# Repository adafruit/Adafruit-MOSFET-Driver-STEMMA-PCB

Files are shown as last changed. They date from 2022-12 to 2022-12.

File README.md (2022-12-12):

## Adafruit Adafruit MOSFET Driver STEMMA PCB

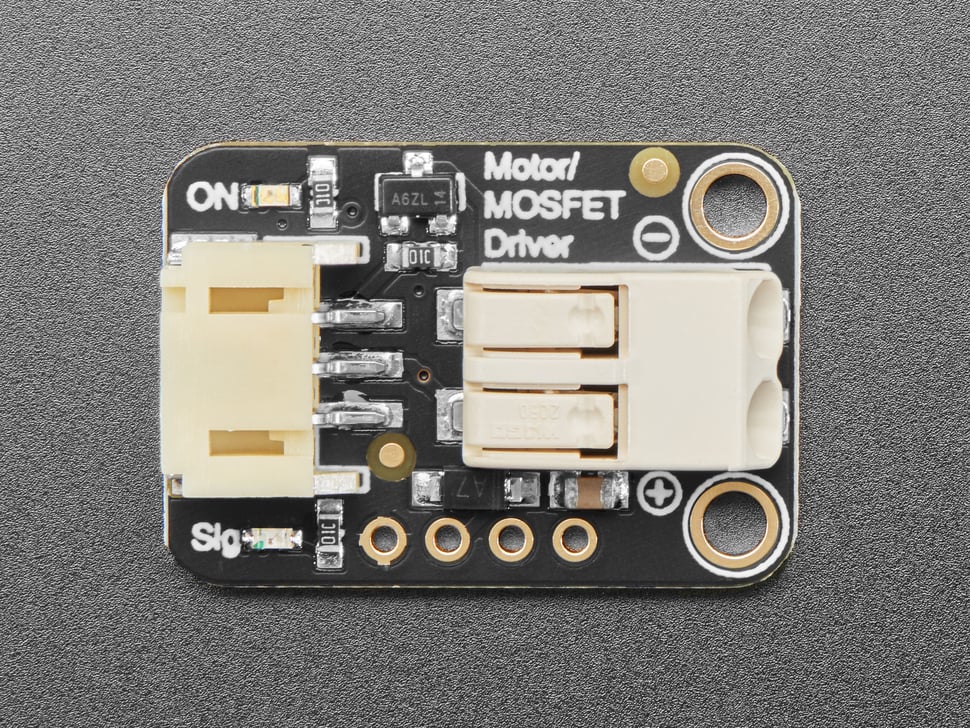
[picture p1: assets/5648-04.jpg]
<a href="http://www.adafruit.com/products/5648"><br/>
Click here to purchase one from the Adafruit shop</a>

PCB files for the Adafruit Adafruit MOSFET Driver STEMMA. 

Format is EagleCAD schematic and board layout
* https://www.adafruit.com/product/5648

### Description

Sparky the Blue Smoke Monster shows up whenever the magic smoke is let of of an electronic component. And his very favorite is whenever folks first start with electronics and robotics: wiring up a motor or solenoid or high power LED is a perfect recipe for getting that blue smoke out of an Arduino or Raspberry Pi. Why? Because these high-current devices can't be connected directly to a GPIO pin on a microcontroller! They need to have a transistor / MOSFET driver, plus a kickback-protection diode that will absorb the inductive 'kick' caused by turning on-and-off motors and solenoids. Without that driver and diode - your tronix will go poof!

We have tutorials on how to wire up the components to create a transistor driver on a breadboard, but its easy to put the diode in backwards, or pick the wrong kind of transistor. And some folks don't want to have the extra breadboard for just controlling a simple motor fan or solenoid. Which is why we designed the Adafruit STEMMA MOSFET Driver for Motors, Solenoids, and LEDs. 

This board has a simple plug-and-play JST PH (2mm pitch) input connector for solderless use. Provide power (from 3V up to 30V) and signal (3V to 20V logic level). On the output are two-output terminal blocks, with one block connected to power and the other switched to ground when the signal level is high. In between is an AO3406 N-Channel MOSFET rated for  30Vds, 3.6A peak, and 70mΩ RdsOn plus a 1N4007 flyback diode.

You can also get to all the signal and power pins on a 0.1" breakout header if desired, but we expect most folks will like using it as a solderless MOSFET-buddy. Great for driving motors, inductors, high power LEDs, single-color LED strips, or other loads up with to 1.5 Amps continuous draw, 3 Amp peak. Note that the JST PH connector itself is only rated for 2 Amp continuous.

### License

Adafruit invests time and resources providing this open source design, please support Adafruit and open-source hardware by purchasing products from [Adafruit](https://www.adafruit.com)!

Designed by Limor Fried/Ladyada for Adafruit Industries.

Creative Commons Attribution/Share-Alike, all text above must be included in any redistribution. 
See license.txt for additional details.

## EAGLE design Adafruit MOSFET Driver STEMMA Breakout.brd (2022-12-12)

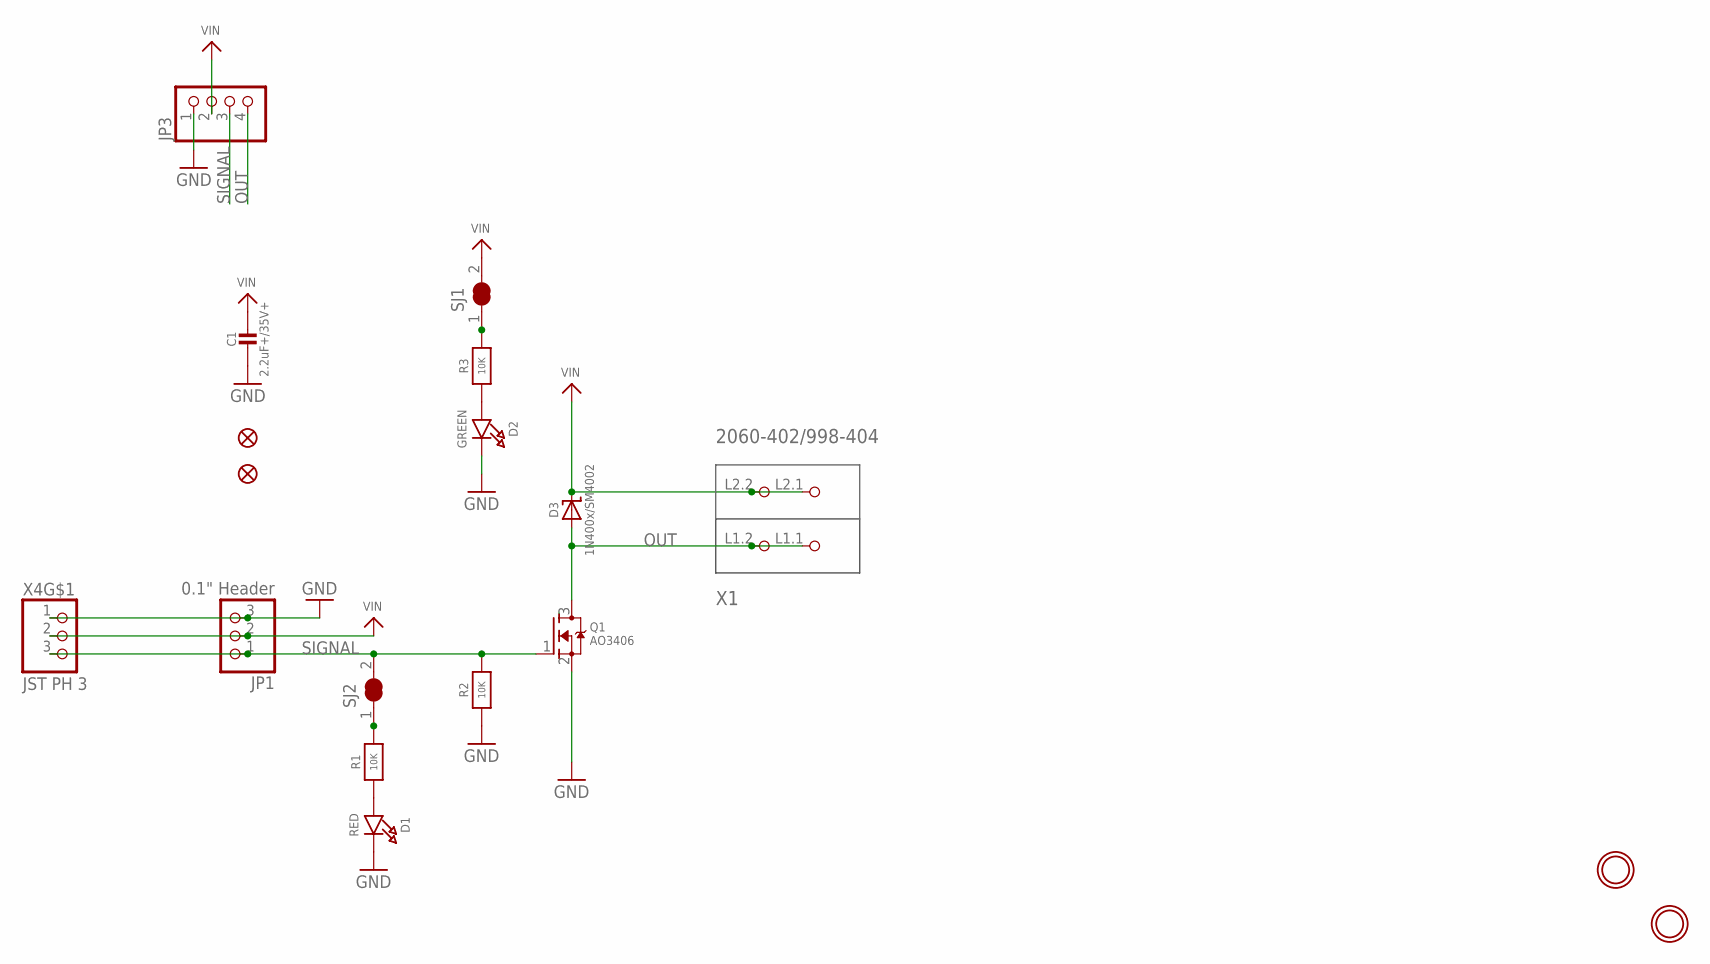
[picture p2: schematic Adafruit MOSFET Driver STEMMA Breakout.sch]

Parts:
C1: 2.2uF+/35V+; 0805-NO
D1: RED; CHIPLED_0603_NOOUTLINE
D2: GREEN; CHIPLED_0603_NOOUTLINE
D3: 1N400x/SM4002; SOD-123
FID2, FID3: FIDUCIAL_1MM
JP1: 0.1" Header; 1X03_OVAL
JP3: HEADER-1X4ROUND; 1X04_ROUND
Q1: AO3406; SOT23-WIDE
R1, R2, R3: 10K; 0603-NO
SJ1, SJ2: SOLDERJUMPER_CLOSED; SOLDERJUMPER_CLOSEDWIRE
U$1, U$8: MOUNTINGHOLE2.5; MOUNTINGHOLE_2.5_PLATED
X1: 2060-402/998-404; P-2060-402/998-404
X4: JST PH 3; JSTPH3

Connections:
GND: C1.2, D1.C, D2.C, JP1.3, JP3.1, Q1.2 (S), R2.1, X4.1
unnamed: R3.2, SJ1.1
unnamed: D1.A, R1.1
unnamed: R1.2, SJ2.1
unnamed: D2.A, R3.1
OUT: D3.A, JP3.4, Q1.3 (D), X1.L1.1 (P1.1), X1.L1.2 (P1.2)
SIGNAL: JP1.1, JP3.3, Q1.1 (G), R2.2, SJ2.2, X4.3
VIN: C1.1, D3.C, JP1.2, JP3.2, SJ1.2, X1.L2.1 (P2.1), X1.L2.2 (P2.2), X4.2

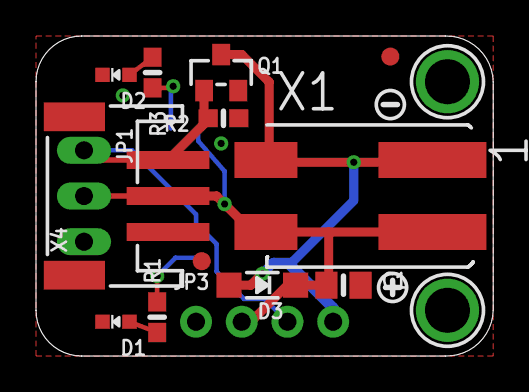
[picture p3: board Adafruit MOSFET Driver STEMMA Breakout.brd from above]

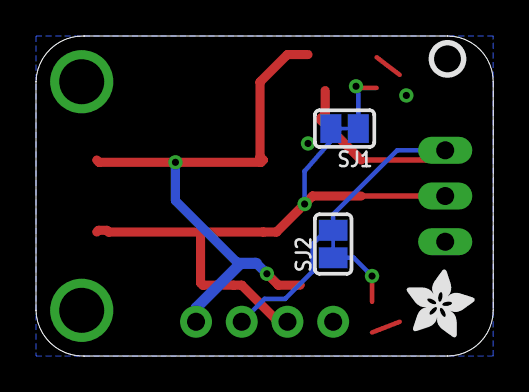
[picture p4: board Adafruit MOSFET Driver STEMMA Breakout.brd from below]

Board: 2 copper layers, 25.4 x 17.8 mm, 36 parts (15 on the bottom side), 8 nets.

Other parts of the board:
PLABEL0: PLABEL0
PLABEL1: PLABEL1
PLABEL2: PLABEL2
PLABEL3: PLABEL3
PLABEL4: PLABEL4
PLABEL5: PLABEL5
PLABEL6: PLABEL6
PLABEL7: PLABEL7
PLABEL8: PLABEL8
PLABEL9: PLABEL9
PLABEL10: PLABEL10
PLABEL11: PLABEL11
PLABEL12: PLABEL12
PLABEL13: PLABEL13
U$3: SYMBOL_PLUS
U$5: PCBFEAT-REV-040
U$9: SYMBOL_MINUS
U$12: ADAFRUIT_3.5MM

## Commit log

2022-12-12 adding cookiecutter output
    [Adafruit MOSFET Driver STEMMA Breakout.brd, Adafruit MOSFET Driver STEMMA Breakout.sch]
2022-12-12 adding measures
    [Adafruit MOSFET Driver STEMMA Breakout.brd]

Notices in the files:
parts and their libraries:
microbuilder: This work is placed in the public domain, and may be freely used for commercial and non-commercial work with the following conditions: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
